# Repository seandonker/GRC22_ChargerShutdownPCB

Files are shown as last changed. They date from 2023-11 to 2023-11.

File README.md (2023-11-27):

# GRC22 Charging Shutdown Board for Guelph's FSAE Club
This board lies inside the external charging enclosure and is responsible for processing certain safety signals.
It then determines if it is safe to activate the battery charger or not. 

**Schematic Theory**<br>
The board takes in three main safety signals: IMD Error, AMS Safety, and Charger Safety. IMD Error indicates the insulation in between the cells of the battery pack 
and the signal faults low when an error is detected. AMS Safety faults low as well when there is an issue with the voltage/temperature/current of any individual cell bank in the battery. Finally, 
charger safety sinks current when no error is present and is allowed to float when an error occurs. The latching logic is the core design challenge of this board. 
The FSAE rulebook has specific descriptions relating to the IMD and AMS signals as once an error is noticed, the output of the board must stay in the error state until 
manually reset (power cycled). This is why latches are required to save the error state. Two RS latches were implemented in combination with RC filters, AND gates, and inverters.
This was done to combat unknown input signal conditions on startup. A full input/output-state circuit trace can be seen in the provided files (ShutdownBoard_Latching_Logic_States).
The relay logic section acts as a chain of switches, so only if  the charge sink, IMD, AMS, E-stop, and interconnect states are all correct, will then the charger and accessories be provided power.

**Board Layout**<br>
The main requirement for the PCB layout was to be able to manufacture on a two layer PCB for cost reasons. The criteria for design were ease of assembly, connector and fuse access,
and the visibility of the indicator LEDs and silkscreen. 

schematic_view

3d_Viewer

PCB_Layout

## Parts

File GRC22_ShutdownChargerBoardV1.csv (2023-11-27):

Source: | C:\GryphonRacingDrive\University of Guelph\Gryphon SAE Racing Team - GRC22\CAD\EV\PCB's\ChargerSafetyPCB\GRC22_ShutdownChargerBoardV1.kicad_sch
Date: | 2023-11-17 5:54:27 PM
Tool: | Eeschema 7.0.8
Generator: | C:\Program Files\KiCad\7.0\bin\scripting\plugins/bom_csv_grouped_by_value.py
Component Count: | 57
Collated Components:
Item | Qty | Reference(s) | Value | LibPart | Footprint | Datasheet | DNP | MANUFACTURER | STANDARD | Sim.Device | Sim.Pins | Sim.Type
1 | 2 | C1, C2 | 100nF | Device:C | Capacitor_SMD:C_0603_1608Metric_Pad1.08x0.95mm_HandSolder | ~
2 | 2 | C3, C4 | .47nF | Device:C | Capacitor_SMD:C_0603_1608Metric_Pad1.08x0.95mm_HandSolder | ~
3 | 3 | D1, D2, D3 | LED | Device:LED | LED_SMD:LED_1206_3216Metric_Pad1.42x1.75mm_HandSolder | ~
4 | 3 | D4, D5, D6 | D | Device:D | Footprints:SOD57-10 | ~ |  |  |  | D | 1=K 2=A
5 | 1 | F2 | Fuse | Device:Fuse | Footprints:FUSE_3557-2 | ~
6 | 4 | H1, H2, H3, H4 | M4_Hole | Mechanical:MountingHole_Pad | MountingHole:MountingHole_4.3mm_M4_DIN965_Pad | ~
7 | 1 | J1 | Signal_In | Connector_Generic:Conn_01x08 | Connector_Molex:Molex_Micro-Fit_3.0_43045-0812_2x04_P3.00mm_Vertical | ~
8 | 1 | J2 | Charger Pwr | Connector_Generic:Conn_01x02 | Connector_Molex:Molex_Micro-Fit_3.0_43650-0215_1x02_P3.00mm_Vertical | ~
9 | 1 | J3 | Relay | Connector_Generic:Conn_01x02 | Connector_Molex:Molex_Micro-Fit_3.0_43650-0215_1x02_P3.00mm_Vertical | ~
10 | 1 | J4 | Minitactor | Connector_Generic:Conn_01x02 | Connector_Molex:Molex_Micro-Fit_3.0_43650-0215_1x02_P3.00mm_Vertical | ~
11 | 1 | J5 | Interlock | Connector_Generic:Conn_01x02 | Connector_Molex:Molex_Micro-Fit_3.0_43650-0215_1x02_P3.00mm_Vertical | ~
12 | 1 | J6 | E-Stop | Connector_Generic:Conn_01x02 | Connector_Molex:Molex_Micro-Fit_3.0_43650-0215_1x02_P3.00mm_Vertical | ~
13 | 1 | J7 | CAN In | Connector_Generic:Conn_01x02 | Connector_Molex:Molex_Micro-Fit_3.0_43650-0215_1x02_P3.00mm_Vertical | ~
14 | 1 | J8 | CAN Out | Connector_Generic:Conn_01x02 | Connector_Molex:Molex_Micro-Fit_3.0_43650-0215_1x02_P3.00mm_Vertical | ~
15 | 1 | J9 | Brd Pwr LED | Connector_Generic:Conn_01x02 | Connector_Molex:Molex_Micro-Fit_3.0_43650-0215_1x02_P3.00mm_Vertical | ~
16 | 1 | J10 | Charger Active LED | Connector_Generic:Conn_01x02 | Connector_Molex:Molex_Micro-Fit_3.0_43650-0215_1x02_P3.00mm_Vertical | ~
17 | 1 | J11 | Fault LED | Connector_Generic:Conn_01x02 | Connector_Molex:Molex_Micro-Fit_3.0_43650-0215_1x02_P3.00mm_Vertical | ~
18 | 2 | K1, K2 | ALQ112 | ALQ112:ALQ112 | Footprints:RELAY_ALQ112 |  |  | PANASONIC | Manufacturer Recommendations
19 | 2 | Q1, Q2 | PMOS | Simulation_SPICE:PMOS | Footprints:RSC002 | https://ngspice.sourceforge.io/docs/ngspice-manual.pdf |  |  |  | PMOS | 1=D 2=G 3=S | VDMOS
20 | 9 | R1, R2, R3, R5, R6, R10, R12, R15, R19 | 470 | Device:R | Resistor_SMD:R_0603_1608Metric_Pad0.98x0.95mm_HandSolder | ~
21 | 2 | R4, R16 | 1K | Device:R | Resistor_SMD:R_0603_1608Metric_Pad0.98x0.95mm_HandSolder | ~
22 | 2 | R11, R13 | 100k | Device:R | Resistor_SMD:R_0603_1608Metric_Pad0.98x0.95mm_HandSolder | ~
23 | 1 | R14 | 120 | Device:R | Resistor_SMD:R_0603_1608Metric_Pad0.98x0.95mm_HandSolder | ~
24 | 2 | R17, R18 | 10k | Device:R | Resistor_SMD:R_0603_1608Metric_Pad0.98x0.95mm_HandSolder | ~
25 | 2 | R22, R23 | 2.2K | Device:R | Resistor_SMD:R_0603_1608Metric_Pad0.98x0.95mm_HandSolder | ~
26 | 1 | TP1 | IMD | Connector:TestPoint | TestPoint:TestPoint_Pad_D1.0mm | ~
27 | 1 | TP2 | AMS | Connector:TestPoint | TestPoint:TestPoint_Pad_D1.0mm | ~
28 | 1 | TP3 | IMD Lat | Connector:TestPoint | TestPoint:TestPoint_Pad_D1.0mm | ~
29 | 1 | TP4 | AMS Lat | Connector:TestPoint | TestPoint:TestPoint_Pad_D1.0mm | ~
30 | 1 | TP5 | Chrg Sink | Connector:TestPoint | TestPoint:TestPoint_Pad_D1.0mm | ~
31 | 1 | U1 | ~ | MC14049B:MC14049B | Footprints:SOIC127P600X175-16N
32 | 2 | U2, U4 | MC14043BDG | MC14043BDG:MC14043BDG | Footprints:SOIC127P600X175-16N
33 | 1 | U3 | MC14081BDG | MC14081BDG:MC14081BDG | Footprints:SOIC127P600X175-14N

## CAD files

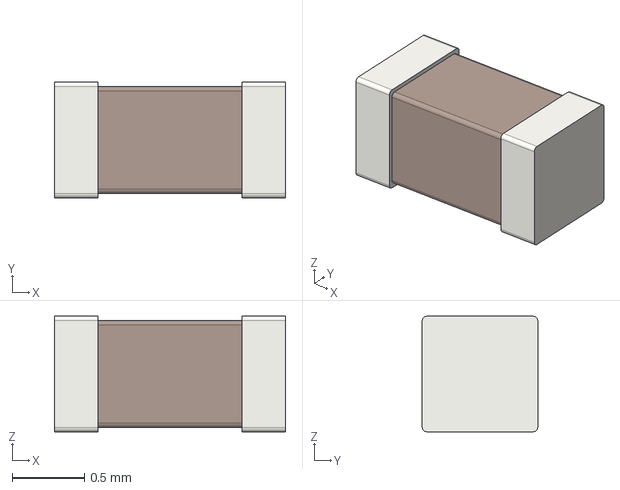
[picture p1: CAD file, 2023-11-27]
CAD/3DModels/C_0603_1608Metric.step
1.60 x 0.8 x 0.8 mm

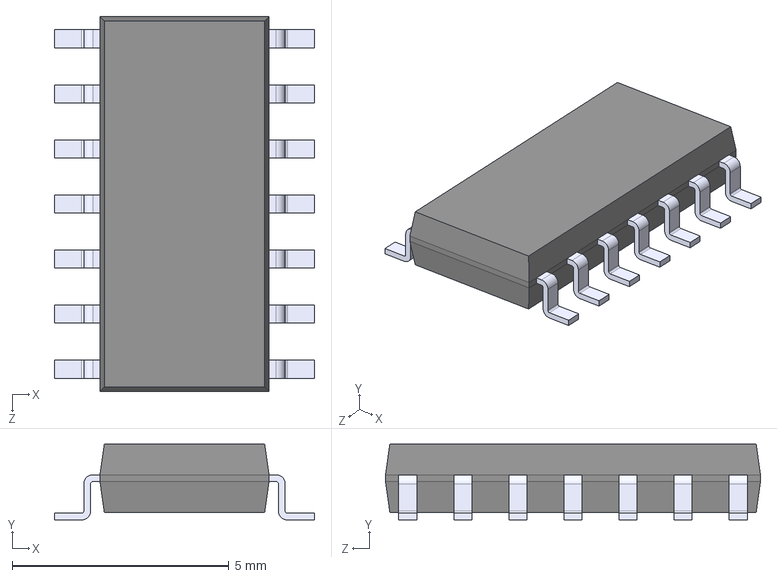
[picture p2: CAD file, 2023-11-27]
CAD/3DModels/SN74LV21ADR.step
6.00 x 1.75 x 8.65 mm

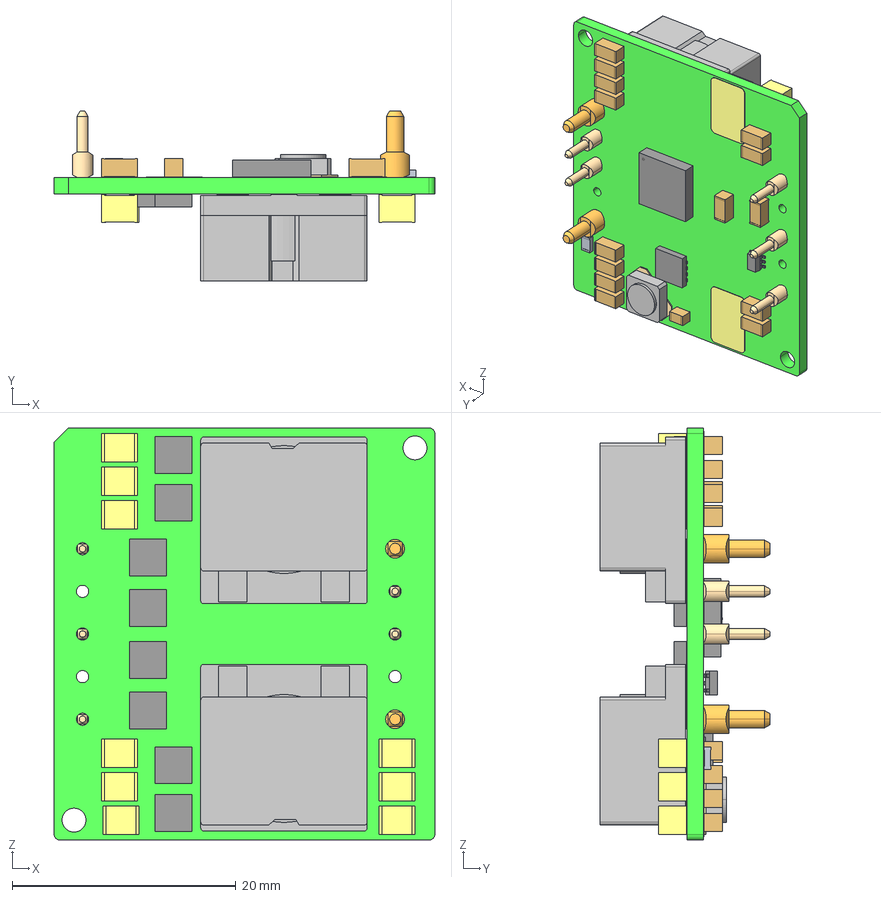
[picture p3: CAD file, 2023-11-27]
CAD/3DModels/i7A_33A_Base_Unit.step
34.0 x 15.2 x 36.8 mm
I7A_PWB
CDEP147 x 2
1210_CAP_2R5MM x 9
MLP_3MMX3MM x 8
1206_CAP_COLOR x 14
TQFP_7X7
CDC4D20_COLOR
0805_CAP_COLOR
0805_RES
LLP-8_COLOR
SC70-5_COLOR
AP00115_LABEL x 2
ZP00167_01 x 2
ZP00166_01 x 5

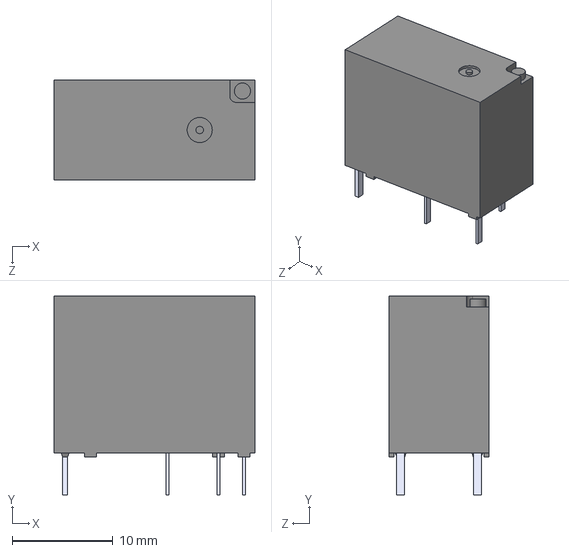
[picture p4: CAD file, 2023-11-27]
CAD/3DModels/ALQ112--3DModel-STEP-56544.STEP
20.0 x 19.8 x 10.0 mm

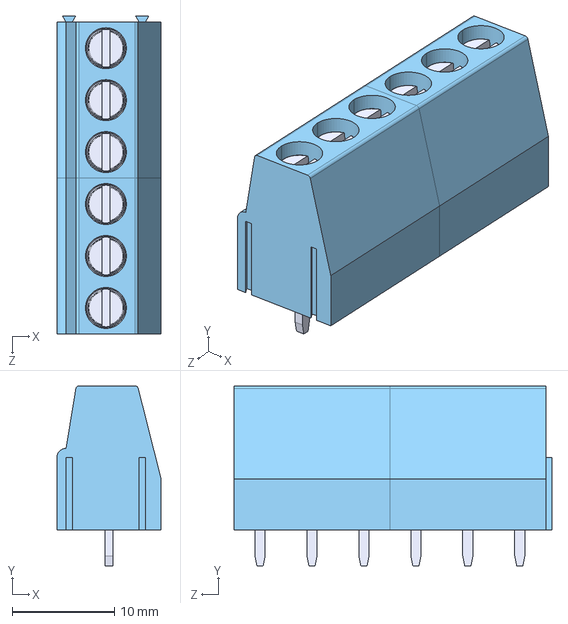
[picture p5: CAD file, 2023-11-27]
CAD/3DModels/CUI_DEVICES_TB004-508-06BE.step
10.2 x 17.6 x 31.1 mm
TB004-508-03P_Blue - S x 2

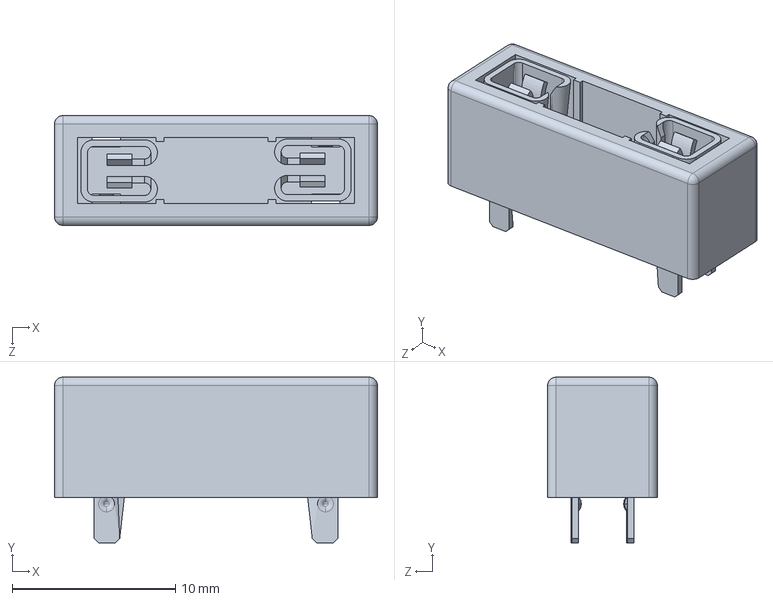
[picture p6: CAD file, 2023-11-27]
CAD/3DModels/3557-2.step
19.8 x 10.2 x 6.73 mm

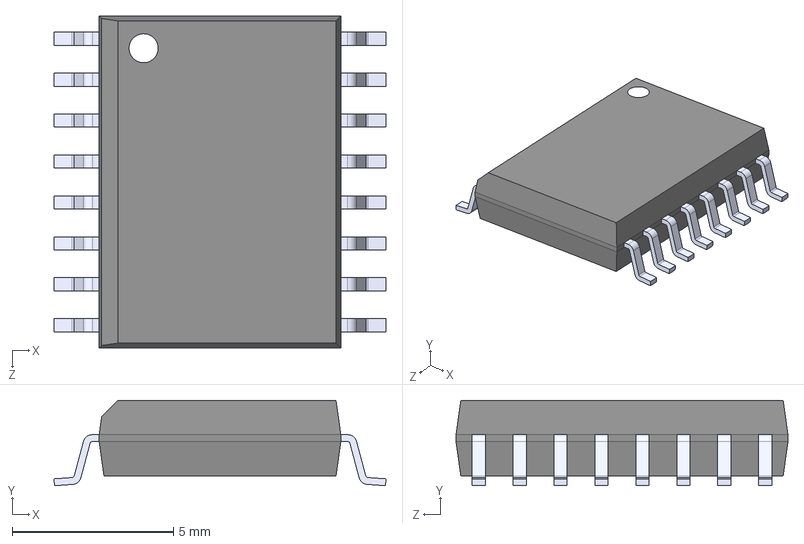
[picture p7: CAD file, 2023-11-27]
CAD/3DModels/SOIC127P1030X265-16N.step
10.3 x 2.65 x 10.3 mm

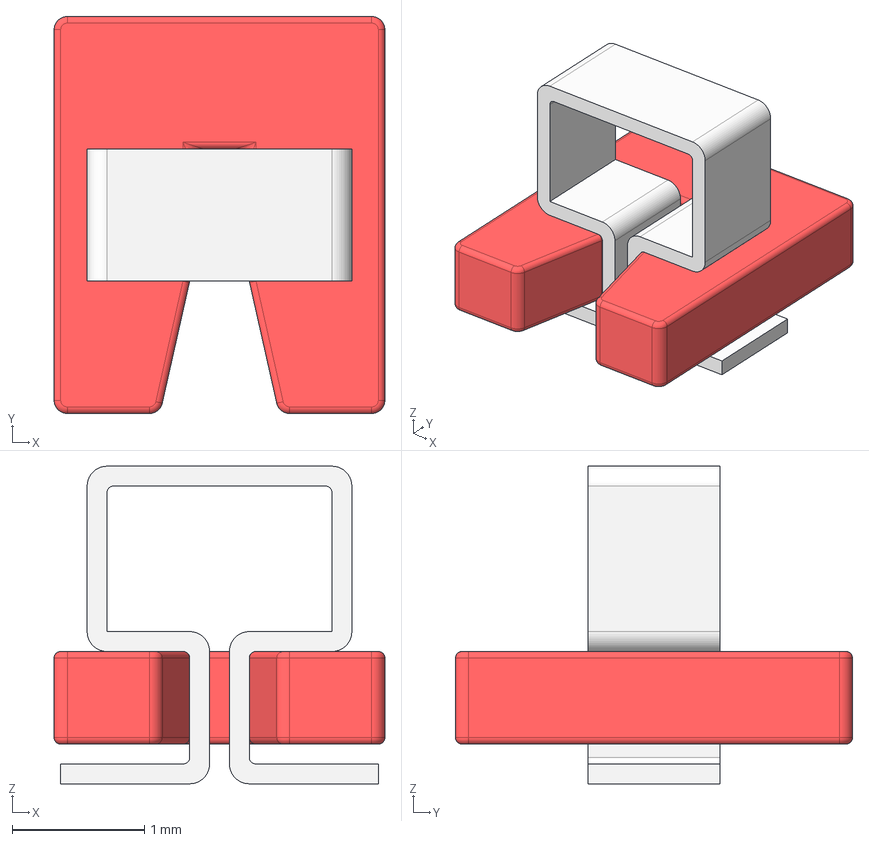
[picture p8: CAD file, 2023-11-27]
CAD/3DModels/5190TR (Red).step
2.50 x 3.00 x 2.40 mm

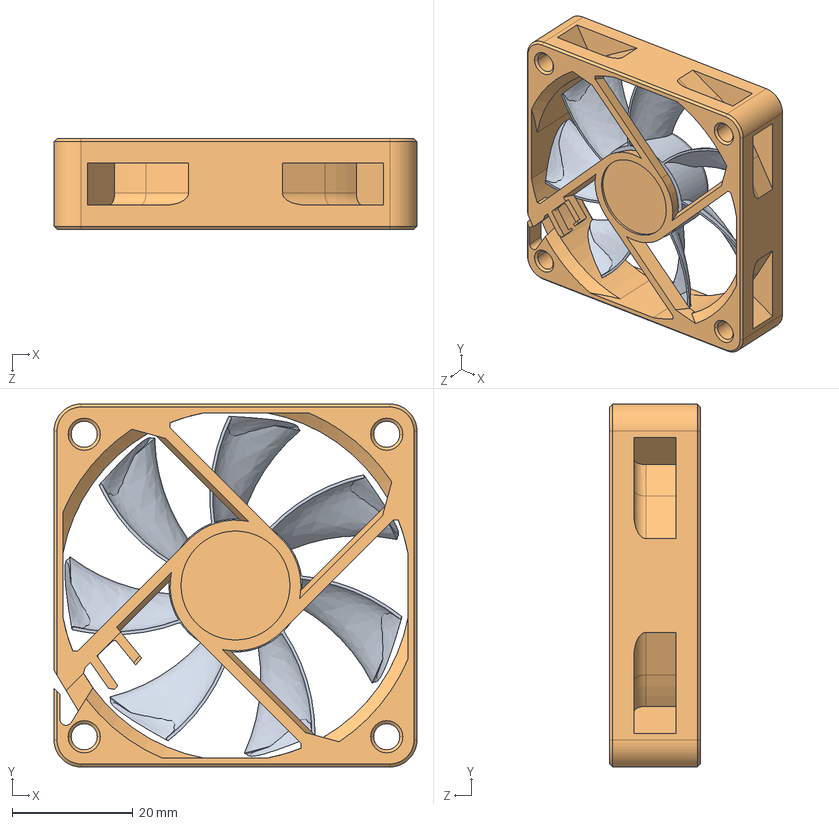
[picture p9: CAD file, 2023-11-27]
CAD/3DModels/SUNON Fan 60x60x15 mm.STEP
60.0 x 60.0 x 15.0 mm
Fan Wheel
Fan-Sunont_60x60x15mm

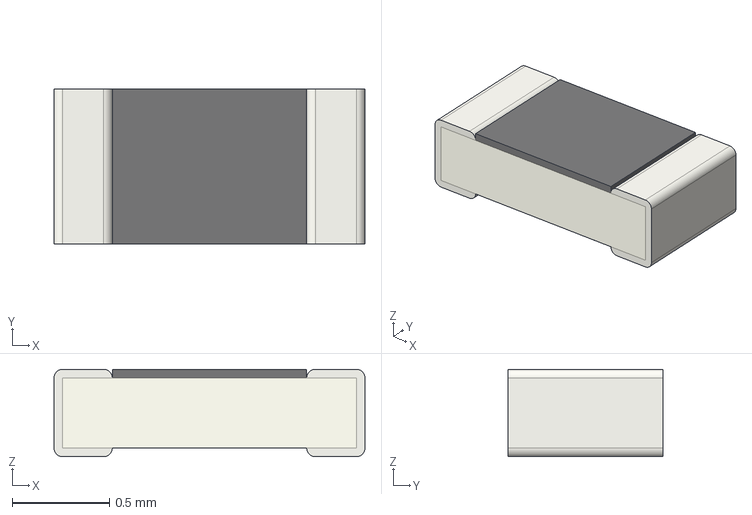
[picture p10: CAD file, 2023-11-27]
CAD/3DModels/R_0603_1608Metric.step
1.60 x 0.8 x 0.45 mm

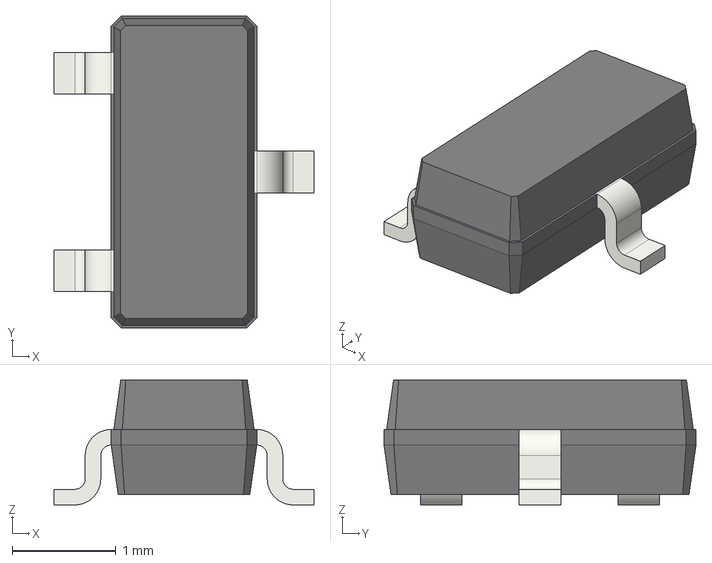
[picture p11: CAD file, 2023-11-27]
CAD/3DModels/SOT-23.step
2.50 x 3.00 x 1.20 mm

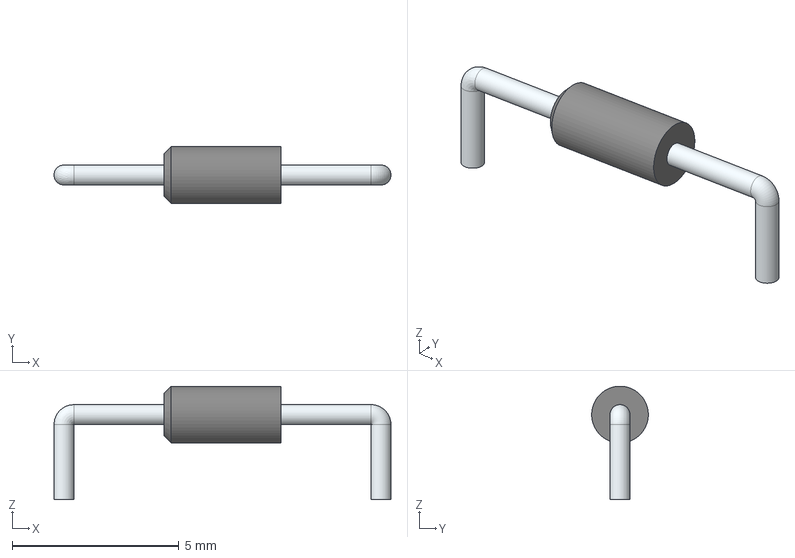
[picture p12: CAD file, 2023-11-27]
CAD/3DModels/BZX55B62-TR.stp
10.1 x 1.70 x 3.40 mm

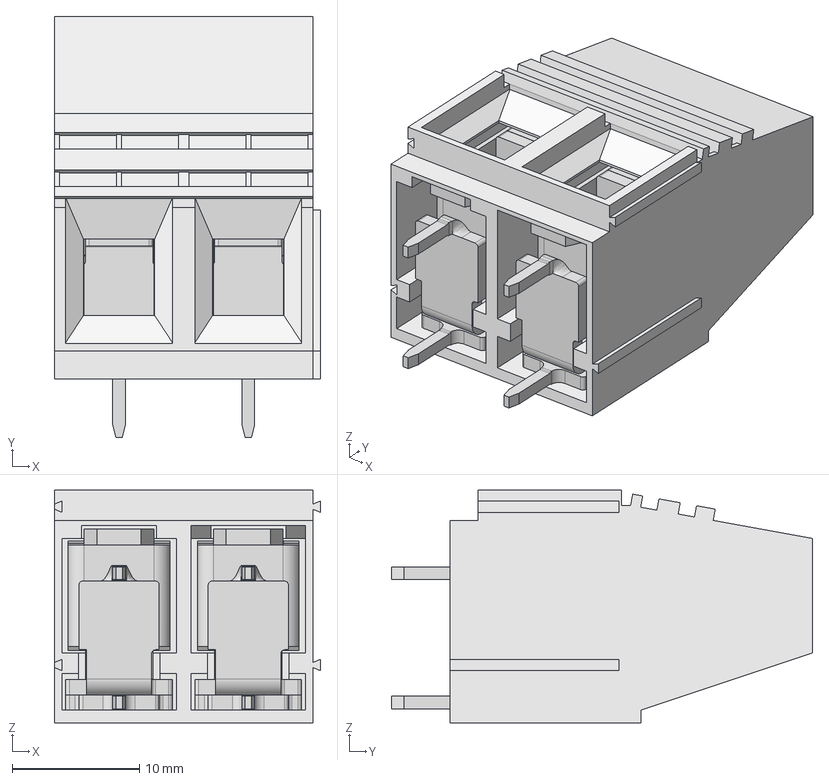
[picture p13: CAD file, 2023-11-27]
CAD/3DModels/691219610002.stp
20.9 x 33.1 x 18.3 mm
6912196100xx_PIN2 x 2
6912196100xx_PIN1 x 2
6912196100xx x 2
6912196100xx_VIS x 2

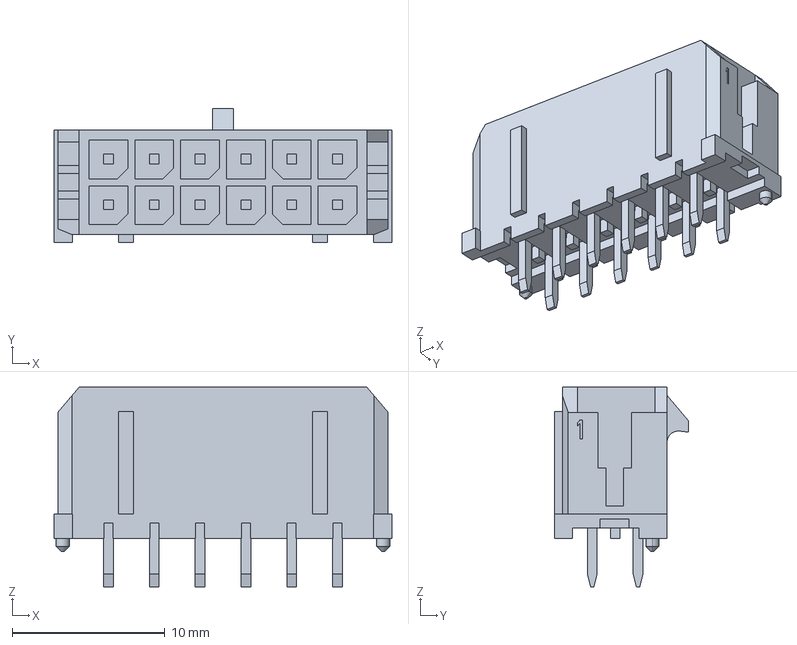
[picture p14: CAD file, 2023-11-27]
CAD/3DModels/430451227.stp
22.1 x 8.77 x 13.1 mm

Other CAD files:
CAD/3DModels/MC14081BDG.step
CAD/3DModels/436500627.stp
CAD/3DModels/436500227-2.stp
CAD/3DModels/0436500427--3DModel-STEP-231308.STEP
CAD/3DModels/0436500327--3DModel-STEP-231308.STEP
CAD/3DModels/0436500427--3DModel-STEP-231308 (1).STEP
CAD/3DModels/0436500427--3DModel-STEP-231308 (2).STEP
CAD/3DModels/430450812.SLDPRT
CAD/3DModels/430450812.STEP
CAD/3DModels/MC14043BDG.step

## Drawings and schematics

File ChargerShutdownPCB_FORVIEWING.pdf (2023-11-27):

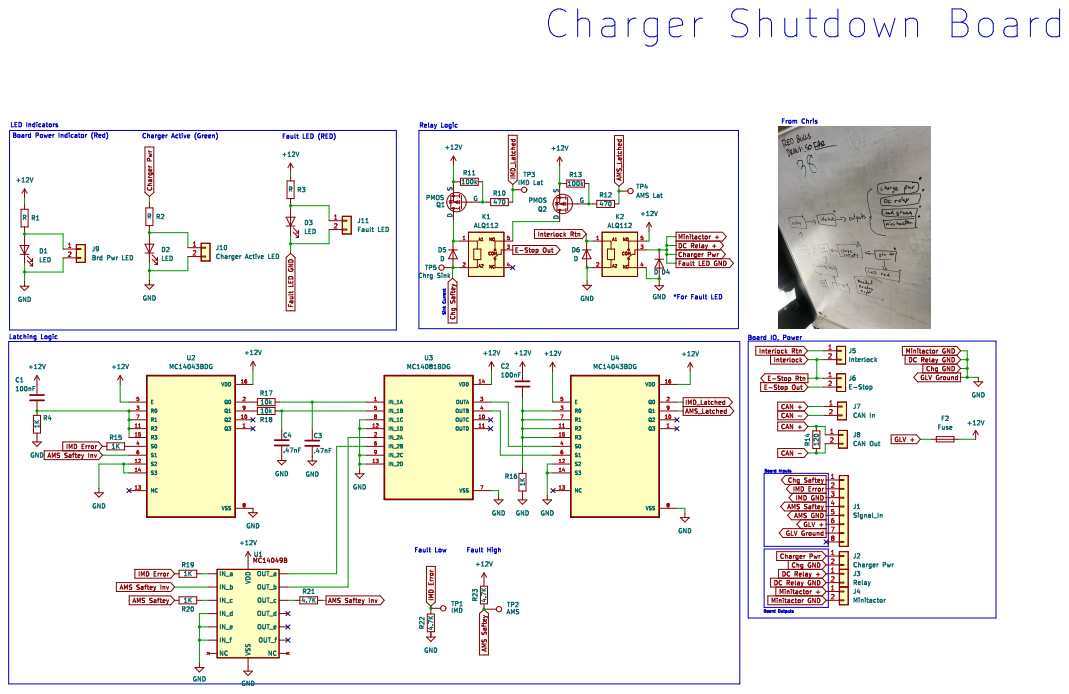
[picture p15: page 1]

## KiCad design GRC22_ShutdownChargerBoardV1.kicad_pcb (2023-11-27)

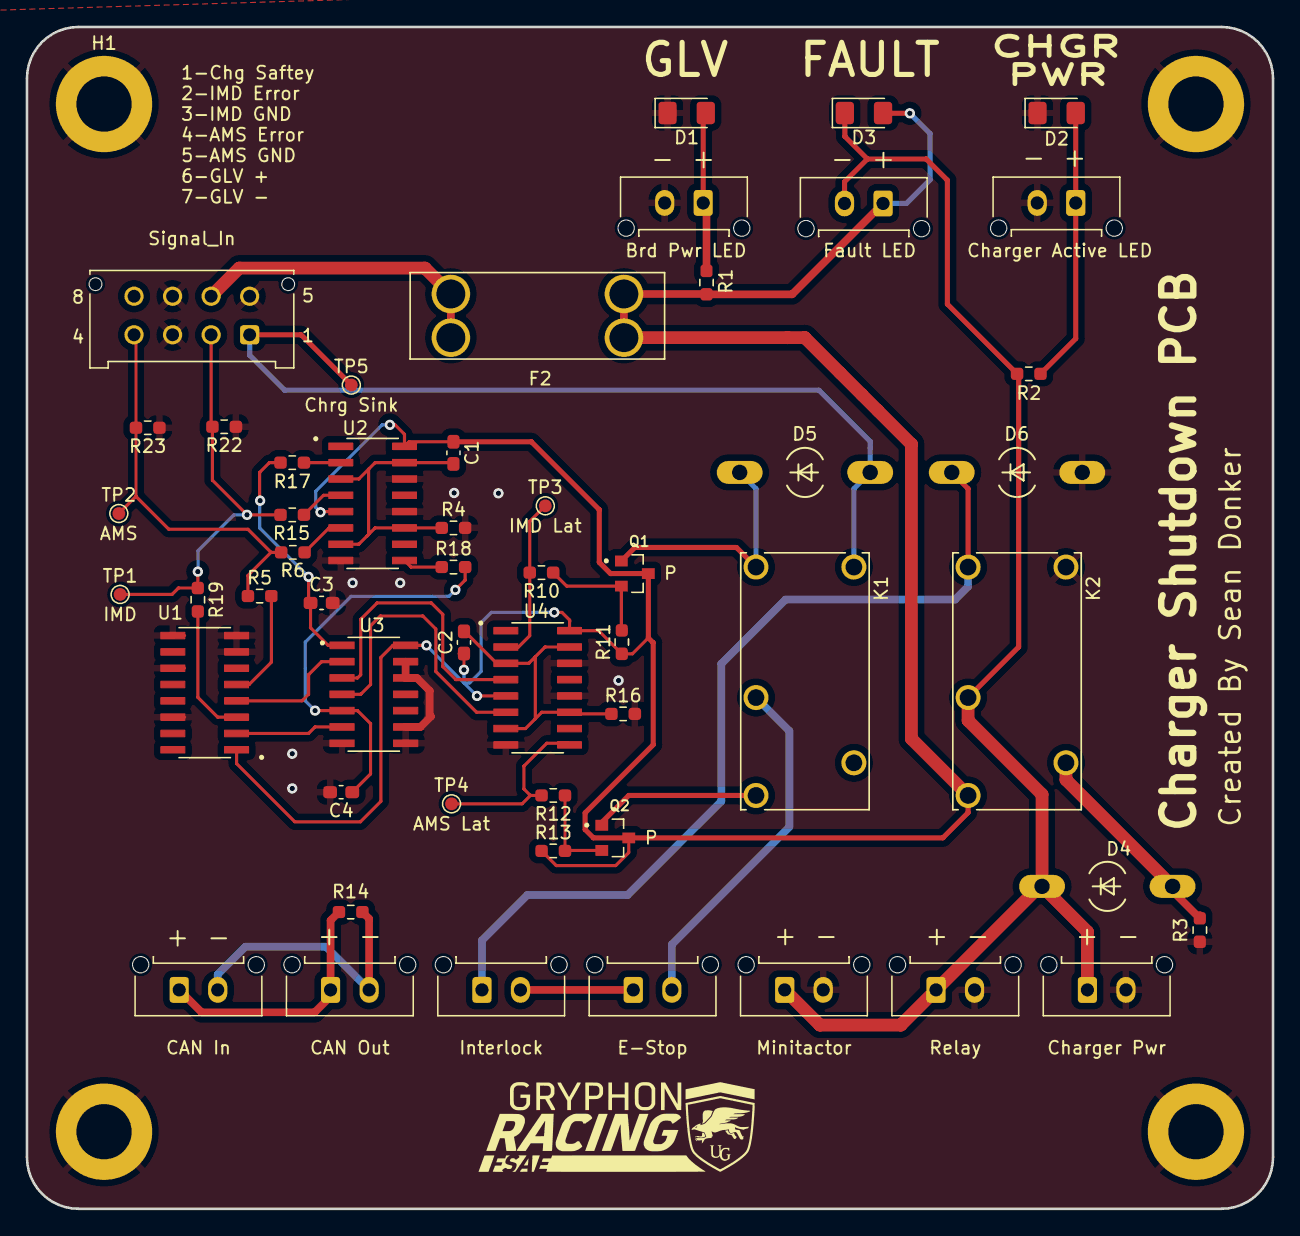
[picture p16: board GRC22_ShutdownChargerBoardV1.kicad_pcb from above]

Board: 2 copper layers, 97.0 x 92.0 mm, 57 parts (0 on the bottom side), 35 nets.

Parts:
C1, C2: 100nF; C_0603_1608Metric_Pad1.08x0.95mm_HandSolder
C3, C4: .47nF; C_0603_1608Metric_Pad1.08x0.95mm_HandSolder
D1, D2, D3: LED; LED_1206_3216Metric_Pad1.42x1.75mm_HandSolder
D4, D5, D6: D; SOD57-10
F2: Fuse; FUSE_3557-2
H1, H2, H3, H4: M4_Hole; MountingHole_4.3mm_M4_DIN965_Pad
J1: Signal_In; Molex_Micro-Fit_3.0_43045-0812_2x04_P3.00mm_Vertical
J2: Charger Pwr; Molex_Micro-Fit_3.0_43650-0215_1x02_P3.00mm_Vertical
J3: Relay; Molex_Micro-Fit_3.0_43650-0215_1x02_P3.00mm_Vertical
J4: Minitactor; Molex_Micro-Fit_3.0_43650-0215_1x02_P3.00mm_Vertical
J5: Interlock; Molex_Micro-Fit_3.0_43650-0215_1x02_P3.00mm_Vertical
J6: E-Stop; Molex_Micro-Fit_3.0_43650-0215_1x02_P3.00mm_Vertical
J7: CAN In; Molex_Micro-Fit_3.0_43650-0215_1x02_P3.00mm_Vertical
J8: CAN Out; Molex_Micro-Fit_3.0_43650-0215_1x02_P3.00mm_Vertical
J9: Brd Pwr LED; Molex_Micro-Fit_3.0_43650-0215_1x02_P3.00mm_Vertical
J10: Charger Active LED; Molex_Micro-Fit_3.0_43650-0215_1x02_P3.00mm_Vertical
J11: Fault LED; Molex_Micro-Fit_3.0_43650-0215_1x02_P3.00mm_Vertical
K1, K2: ALQ112; RELAY_ALQ112
Q1, Q2: PMOS; RSC002
R1, R2, R3, R5, R6, R10, R12, R15, R19: 470; R_0603_1608Metric_Pad0.98x0.95mm_HandSolder
R4, R16: 1K; R_0603_1608Metric_Pad0.98x0.95mm_HandSolder
R11, R13: 100k; R_0603_1608Metric_Pad0.98x0.95mm_HandSolder
R14: 120; R_0603_1608Metric_Pad0.98x0.95mm_HandSolder
R17, R18: 10k; R_0603_1608Metric_Pad0.98x0.95mm_HandSolder
R22, R23: 2.2K; R_0603_1608Metric_Pad0.98x0.95mm_HandSolder
TP1: IMD; TestPoint_Pad_D1.0mm
TP2: AMS; TestPoint_Pad_D1.0mm
TP3: IMD Lat; TestPoint_Pad_D1.0mm
TP4: AMS Lat; TestPoint_Pad_D1.0mm
TP5: Chrg Sink; TestPoint_Pad_D1.0mm
U1: SOIC127P600X175-16N
U2, U4: MC14043BDG; SOIC127P600X175-16N
U3: MC14081BDG; SOIC127P600X175-14N

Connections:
+12V: C1.1, C2.1, D3.2 (A), F2.2, J11.1, K2.5, Q1.3 (S), Q2.3 (S), R1.1, R11.1, R13.1, U1.1 (VDD), U2.5 (E), U2.16 (VDD), U3.14 (VDD), U4.5 (E), U4.16 (VDD)
AMS GND: C3.2, C4.2, D1.1 (K), D2.1 (K), D6.2 (A), H1.1, H2.1, H3.1, H4.1, J1.3, J1.5, J1.7, J2.2, J3.2, J4.2, J9.2, J10.2, K2.2, R3.2, R4.2, R16.2, R22.1, R23.1, U1.7 (IN_c), U1.8 (VSS), U1.9 (IN_d), U1.11 (IN_e), U1.14 (IN_f), U2.8 (VSS), U2.12 (S2), U2.14 (S3), U3.7 (VSS), U3.8 (IN_1C), U3.9 (IN_2C), U3.12 (IN_1D), U3.13 (IN_2D), U4.8 (VSS), U4.12 (S2), U4.14 (S3)
AMS Saftey: J1.4, R5.1, R6.1, R23.2, TP2.1
AMS_Latched: R12.2, TP4.1, U4.9 (Q1)
CAN +: J7.1, J8.1, R14.2
CAN -: J7.2, J8.2, R14.1
Charger Pwr: D3.1 (K), D4.1 (K), J2.1, J3.1, J4.1, J11.2, K2.3, R2.1
Chg Saftey: D5.2 (A), J1.1, K1.2, TP5.1
E-Stop Out: J6.2, K1.3
E-Stop Rtn: J5.2, J6.1
GLV +: F2.1, J1.6
IMD Error: J1.2, R15.1, R19.1, R22.2, TP1.1
IMD_Latched: R10.2, TP3.1, U4.2 (Q0)
Interlock Rtn: D6.1 (K), J5.1, K2.1
unnamed: D1.2 (A), J9.1, R1.2
unnamed: D2.2 (A), J10.1, R2.2
unnamed: D4.2 (A), K2.4, R3.1
unnamed: D5.1 (K), K1.1, Q1.1 (D)
unnamed: Q1.2 (G), R10.1, R11.2
unnamed: K1.5, Q2.1 (D)
unnamed: Q2.2 (G), R12.1, R13.2
unnamed: R19.2, U1.3 (IN_a)
unnamed: R5.2, U1.5 (IN_b)
unnamed: U1.2 (OUT_a), U3.6 (IN_2B)
unnamed: U1.4 (OUT_b), U3.2 (IN_2A)
unnamed: R17.1, U2.2 (Q0)
unnamed: R18.1, U2.9 (Q1)
unnamed: C1.2, R4.1, U2.3 (R0), U2.7 (R1), U2.11 (R2), U2.15 (R3)
unnamed: R15.2, U2.4 (S0)
unnamed: R6.2, U2.6 (S1)
unnamed: C3.1, R17.2, U3.1 (IN_1A)
unnamed: C4.1, R18.2, U3.5 (IN_1B)
unnamed: U3.3 (OUTA), U4.4 (S0)
unnamed: U3.4 (OUTB), U4.6 (S1)
unnamed: C2.2, R16.1, U4.3 (R0), U4.7 (R1), U4.11 (R2), U4.15 (R3)

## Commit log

2023-11-27 First file upload
    [GRC22_ShutdownChargerBoardV1.csv, GRC22_ShutdownChargerBoardV1.kicad_pcb]
2023-11-27 Added folders
    [0436500327--3DModel-STEP-231308.STEP, 0436500427--3DModel-STEP-231308 (1).STEP, 0436500427--3DModel-STEP-231308 (2).STEP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]

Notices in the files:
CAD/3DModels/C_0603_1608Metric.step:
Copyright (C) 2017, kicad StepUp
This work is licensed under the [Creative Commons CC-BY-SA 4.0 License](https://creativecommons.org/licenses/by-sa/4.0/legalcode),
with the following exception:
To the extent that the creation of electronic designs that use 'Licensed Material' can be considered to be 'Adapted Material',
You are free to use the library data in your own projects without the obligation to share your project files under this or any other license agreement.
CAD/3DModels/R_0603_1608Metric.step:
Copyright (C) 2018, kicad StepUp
